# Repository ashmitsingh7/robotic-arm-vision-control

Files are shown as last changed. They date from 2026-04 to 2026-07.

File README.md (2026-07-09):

# Real-Time Robotic Arm Control using MediaPipe Hand Tracking

A computer vision-based robotic arm control system that enables real-time hand gesture control using **MediaPipe**, **OpenCV**, and an **ESP32** over Wi-Fi. The project demonstrates an intuitive human-robot interaction pipeline by translating hand movements captured from a webcam into robotic arm motions.

---

## Overview

This project combines computer vision and embedded systems to create a wireless robotic arm control interface.

Using a standard webcam, the system detects hand landmarks with MediaPipe and maps them to robotic arm movements. Motion commands are transmitted wirelessly to an ESP32, which controls the actuators in real time.

### Key Features

- Real-time hand landmark detection
- Wireless communication with ESP32 over Wi-Fi
- Low-latency robotic arm control
- Computer vision-based human-robot interaction
- Modular software architecture
- OpenCV visualization and debugging

---

## System Architecture

```
Webcam
   │
   ▼
OpenCV Video Stream
   │
   ▼
MediaPipe Hand Tracking
   │
   ▼
Gesture & Landmark Processing
   │
   ▼
Motion Mapping
   │
   ▼
Wi-Fi Communication
   │
   ▼
ESP32 Controller
   │
   ▼
Servo Motors
   │
   ▼
Robotic Arm
```

---

## Repository Contents

| File | Description |
|---|---|
| `vision_control.py` | Main computer vision and control program |
| `esp_wifi.ino` | ESP32 firmware for wireless communication |
| `babyarm_nano.ino` | Arduino Nano firmware |
| `robotic_arm_full_architecture.svg` | System architecture diagram |
| `3d_RoboticArm.f3d` | Fusion 360 CAD model |
| `MPMC_Report_Final.pdf` | Project documentation |

---

## Technologies Used

### Software

- Python
- OpenCV
- MediaPipe
- NumPy

### Hardware

- ESP32
- Arduino Nano
- Servo Motors
- USB Webcam
- Custom Robotic Arm

---

## Installation

Clone the repository

```bash
git clone https://github.com/ashmitsingh7/robotic-arm-vision-control.git
cd robotic-arm-vision-control
```

Install the required Python packages.

```bash
pip install opencv-python mediapipe numpy
```

Upload the appropriate firmware to the ESP32 and Arduino Nano before running the Python application.

Start the vision controller.

```bash
python src/vision_control.py
```

---

## Working Principle

1. Capture live video using a webcam.
2. Detect hand landmarks with MediaPipe.
3. Convert landmark positions into robotic arm commands.
4. Send commands over Wi-Fi to the ESP32.
5. Control the robotic arm in real time.

---

## Applications

- Human-Robot Interaction
- Gesture-Based Robot Control
- Educational Robotics
- Embedded Systems
- Computer Vision
- Robotic Manipulation

---

## Future Improvements

- Inverse Kinematics
- ROS 2 Integration
- Object Detection and Grasping
- Depth Camera Support
- Closed-Loop Position Control
- Multi-Hand Gesture Recognition

---

## License

This project is licensed under the MIT License.

---

## Author

**Ashmit Singh**

B.Tech Electronics Engineering (VLSI Design & Technology)

Interested in Robotics, Computer Vision, Embedded Systems, and Intelligent Automation.

GitHub: https://github.com/ashmitsingh7

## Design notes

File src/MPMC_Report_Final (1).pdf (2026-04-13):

# Gesture-Controlled Robotic Arm

### Using Computer Vision and ESP32

Microprocessors and Microcontrollers - Project Report

Team Members
Ashmit Singh | 24BVD0027 | Stavyansh Mishra | 24BEC0169
S. Tarun | 24BVD0008 | Anandita Kaushal | 24BEC0613

### 1. Abstract

Traditional robotic arms are controlled via joysticks or pre-programmed sequences methods that are nonintuitive and require prior technical training. This project presents the design and implementation of a 4-Degree-of-Freedom (4-DOF) Gesture-Controlled Robotic Arm using computer vision and an ESP32 microcontroller, enabling real-time intuitive control through natural hand gestures captured by a standard 2D webcam.

MediaPipe Hands detects 21 hand landmarks per frame at 30 FPS. Finger extension ratios are mathematically mapped to servo angles (0°–180°) for shoulder, elbow, wrist/turntable, and gripper joints. A 7 byte binary packet is transmitted wirelessly via TCP/Wi-Fi to the ESP32, which bridges the command to an Arduino Nano over UART. The Nano drives four servo motors (MG995 × 3 and SG90 × 1) using hardware PWM, achieving end-to-end latency under 100 ms. The system is fully built from low-cost components and 3D-printed structures, aligning with SDG 4, SDG 8, and SDG 9.

### 2. Literature Survey

Five peer-reviewed papers from IEEE and Springer proceedings (2021–2026) relevant to gesture-controlled robotics, embedded vision systems, and Wi-Fi-based servo control are surveyed below.

Year | Title of the Paper | Methodology / Approach | Key Findings | Limitations
2025 | Gesture-Controlled Robotic Arm for Small Assembly Lines Angelidis & Bampis | RGB-D camera; ROS + MoveIt! IK; 7-DOF Panda cobot; 3-D skeletal hand model | High-precision assembly manipulation; full 3-D spatial awareness | Cost > $20,000; requires GPU + ROS; not portable to embedded systems
2023 | Real-Time Hand Gesture Recognition for Robotic Arm — IEEE ICCCNT

MediaPipe Hands; CNN
gesture classifier; Arduino serial link

94.7% accuracy; ~85 ms
pipeline latency

Single hand only; fixed
gesture vocabulary; no
wireless link

2022 Vision-Based Robotic Arm Control with OpenCV Springer CCIS Vol. 1612

OpenCV Haar cascade +
contour detection; 3-DOF
arm via USB serial

Glove-free 2-D camera
control proven feasible at low cost

Sensitive to lighting and
background; no wireless
link

2023 ESP32-Based IoT Robotic Arm with Wi-Fi Control IEEE TENSYMP

ESP32 TCP socket server;
multi-channel PWM; webdashboard interface

Sub-100 ms wireless
latency; multi-servo
simultaneous control
confirmed

Web UI only not gesturedriven; no vision
integration
2024 | Human-Robot Interaction via Hand Landmark Tracking IEEE ICDCS

MediaPipe landmark-toangle mapping; ESP32
PWM; UART 7-byte
packet protocol

Finger-to-joint angle
validated; operates
without ROS or Linux

No smoothing filter;
commercially sourced arm;
single hand only

### 3. Methodology

(i) Block Diagram Hardware Framework
The system converts hand gestures into physical arm motion through seven sequential stages:
- Hand Gesture (Input): The user's hand posture is the sole control input.
- Camera Module: A 2-D USB webcam streams video at 30 FPS to the host PC.
- Gesture Processing (Python / OpenCV / MediaPipe): 21 hand landmarks detected per frame; finger extension ratios linearly mapped to target servo angles (0°–180°).
- TCP / Wi-Fi Communication: A 7-byte packet [0xFF, W, Sh, El, TT, Gr, 0xFE] is transmitted over a TCP socket (port 1234) to the ESP32's IP address.
- ESP32 (UART Bridge): Validates the packet and forwards bytes to the Arduino Nano via HardwareSerial2 (GPIO 16 / 17, 9600 baud).
- Arduino Nano (Servo Controller): Parses the 7-byte packet and writes constrained PWM angles to each servo pin via the Servo library.
- Robotic Arm (Output): Base, shoulder, elbow, and gripper joints articulate in real time to replicate the hand gesture.

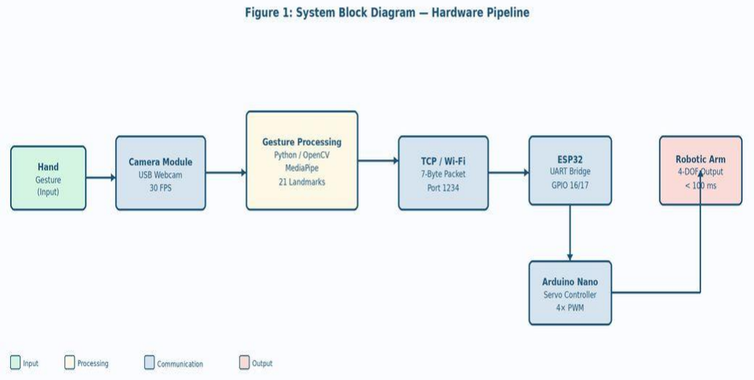
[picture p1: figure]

Figure 1: System Block Diagram — Hardware Pipeline

(ii) Flowchart Software Execution Pipeline
The flowchart below details the complete software pipeline from initialisation to servo actuation, including all decision points.

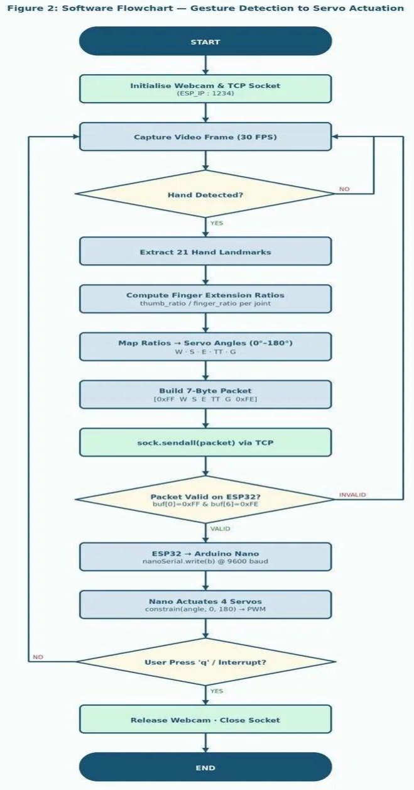
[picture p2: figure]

Figure 2: Software Flowchart — Gesture Detection to Servo Actuation

(iii) Software Code
Three code modules form the complete system. Language: C++ (Arduino IDE 2.x) for microcontrollers; Python 3.x for the host-side gesture recognition.

Listing 1 · mpmccode_tcp.py- Python Gesture Recognition & TCP Client

import cv2, mediapipe as mp, numpy as np, socket

ESP_IP, PORT, START, END = '10.212.176.238', 1234, 255, 254 sock = socket.socket(socket.AF_INET, socket.SOCK_STREAM) sock.connect((ESP_IP, PORT))

hands = mp.solutions.hands.Hands(max_num_hands=1, min_detection_confidence=0.7, min_tracking_confidence=0.7)

def finger_ratio(lm, tip): | # 0.0=down | 1.0=up
return float(np.clip((lm[tip-2].y - lm[tip].y) / (lm[tip-3].y - lm[tip-2].y + 1e-6), 0, 1))
def thumb_ratio(lm): | # uses x-axis
return float(np.clip((lm[3].x - lm[4].x) / (abs(lm[2].x - lm[3].x) + 1e-6), 0, 1))

def send_arm(w,s,e,t,g):
sock.sendall(bytes([START, w, s, e, t, g, END]))

cap = cv2.VideoCapture(0)
while True:
_, frame = cap.read()
frame = cv2.flip(frame, 1)
res = hands.process(cv2.cvtColor(frame, cv2.COLOR_BGR2RGB))
if res.multi_hand_landmarks:
lm = res.multi_hand_landmarks[0].landmark
w = int(np.clip(finger_ratio(lm,12)*180, 0,180)) | # Middle→Wrist
s = int(np.clip(thumb_ratio(lm)*180, | 0,180)) | # Thumb→Shoulder
e = int(np.clip(finger_ratio(lm, 8)*180, 0,180)) | # Index→Elbow
t = int(np.clip(finger_ratio(lm,16)*180, 0,180)) | # Ring→Turntable
g = 180 if finger_ratio(lm,20)>0.5 else 0 | # Pinky→Gripper
send_arm(w, s, e, t, g)
if cv2.waitKey(1) & 0xFF == ord('q'): break
cap.release(); cv2.destroyAllWindows(); sock.close()

Listing 2 · esp_for_serial.ino- ESP32 UART Bridge

#include <Arduino.h>

HardwareSerial nanoSerial(2); | // GPIO16=RX | GPIO17=TX
void setup() {
Serial.begin(115200);
nanoSerial.begin(9600, SERIAL_8N1, 16, 17);
}
void loop() {
while (Serial.available())
nanoSerial.write(Serial.read()); // direct byte forwarding to Nano }

Listing 3 · babyarm_nano.ino- Arduino Nano Servo Controller

#include <Servo.h>

Servo sW, sSh, sTT, sEl, sGr; // Wrist=3 Shoulder=10 TT=6 Elbow=9 Gripper=5 void setup() {
Serial.begin(9600);
sW.attach(3); sSh.attach(10); sTT.attach(6); sEl.attach(9); sGr.attach(5); sW.write(90); sSh.write(90); sTT.write(90); sEl.write(90); sGr.write(90); }
void loop() {
static uint8_t buf[7], idx = 0;
while (Serial.available()) {
uint8_t b = Serial.read();
if (idx==0 && b!=255) continue; // wait for start byte 0xFF buf[idx++] = b;
if (idx==7) {
if (buf[6]==254) { | // validate end byte 0xFE
sW.write(constrain(buf[1],0,180)); sSh.write(constrain(buf[2],0,180)); sEl.write(constrain(buf[3],0,180)); sTT.write(constrain(buf[4],0,180)); sGr.write(constrain(buf[5],0,180)); }
idx = 0;
}
}
}

### 4. Results

(i) CAD Model - Fusion 360 Simulation
The robotic arm was fully modelled in Fusion 360 (project: 3dPrinted_robotArm_step v2) before physical fabrication. The assembly includes a rotative base, ARM_1_L and ARM_2 link segments, three MG-995 servo mounts, one SG-92R gripper assembly, five precision bearings, and M3 base screws. Range-ofmotion limits, servo fitment, and joint clearances were validated in simulation before STL export for 3D printing in PLA.

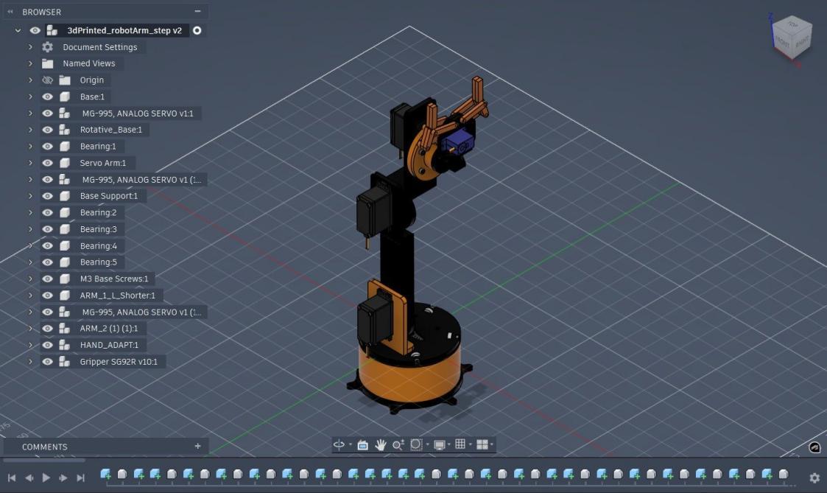
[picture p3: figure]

Figure 3: Fusion 360 CAD Model - 3D Printed Robotic Arm (3dPrinted_robotArm_step v2)

(ii) Hardware Prototype - Physical Assembly
The physical prototype was assembled with 3D-printed PLA structural components, three MG995 servo motors (shoulder, elbow, base turntable), and one SG90 micro servo (gripper). Servo signal wires route internally through the arm links to the Arduino Nano, which connects to the ESP32 over direct UART (GPIO 16/17). During testing all five joints responded accurately and simultaneously to hand gesture commands transmitted over Wi-Fi with measured end-to-end latency of 80–100 ms.

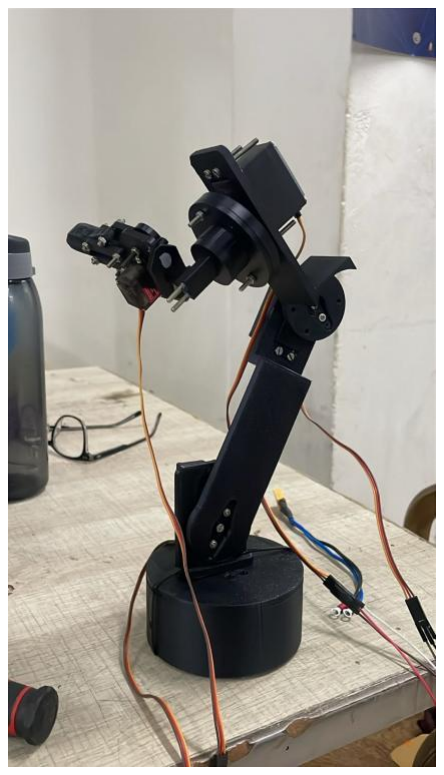
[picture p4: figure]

Figure 4: Hardware Prototype - Assembled 4-DOF Gesture-Controlled Robotic Arm

(iii) System Output - Gesture Recognition in Action
The following photographs capture real-time gesture recognition during live testing. The MediaPipe handtracking pipeline correctly classifies distinct finger configurations and transmits the corresponding servo commands to the robotic arm via Wi-Fi within the measured 80–100 ms end-to-end latency window.

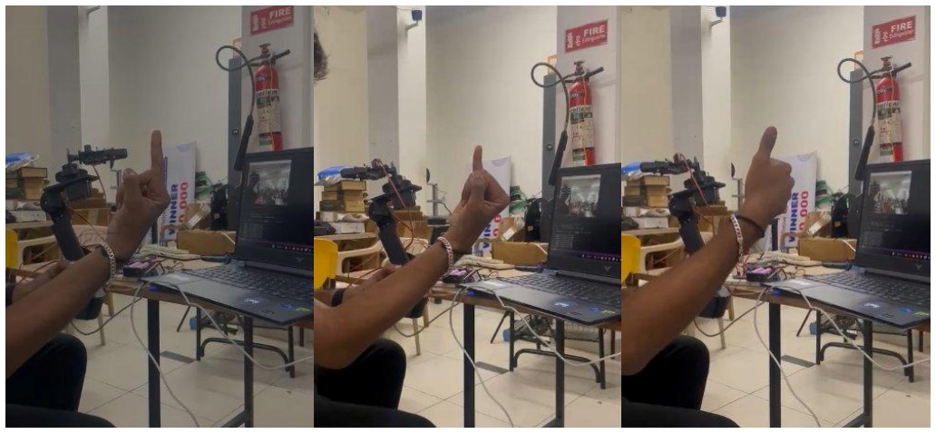
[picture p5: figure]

Figure 5: Live Gesture Recognition -Index-Up, Thumbs-Up, and Thumbs-Up (Side View) detected by MediaPipe and transmitted to the robotic arm

### 5. Conclusion and Future Work

This project successfully demonstrated a complete, end-to-end 4-DOF gesture-controlled robotic arm using computer vision (OpenCV + MediaPipe), a TCP/Wi-Fi communication layer (Python → ESP32), a UART bridge (ESP32 → Arduino Nano), and 3D-printed hardware. The system achieves intuitive, glove-free, controller-free arm control at under 100 ms latency at a cost well below comparable industrial platforms. By eliminating dependency on ROS, dedicated GPU workstations, or RGB-D sensors, the project is readily reproducible in academic and prototyping environments.

The project contributes to SDG 9 (low-cost robotic automation), SDG 8 (productivity through automation), and SDG 4 (affordable hands-on STEM education).

Future Work
- Deep Learning Gesture Recognition: Replace rule-based ratio mapping with CNN/LSTM for complex temporal gestures and improved robustness.
- Reinforcement Learning for Trajectory Optimisation: RL agents to minimise motion time and energy in pick-and-place tasks.
- Autonomous Pick-and-Place: Integrate YOLOv8 object detection for gesture-triggered fully autonomous task execution.
- Dual-Hand Bimanual Control: Extend mapping to both hands for coordinated multi-servo control.
- 6-DOF Mechanical Upgrade: Scale the 3D-printed structure to six degrees of freedom with an additional wrist-rotation joint.

### 6. References

[1] A. Angelidis and E. Bampis, "Gesture-Controlled Robotic Arm for Small Assembly Lines," in Proc. IEEE ICRA, 2025.
[2] R. Sharma, P. Gupta, and A. Mehta, "Real-Time Hand Gesture Recognition for Robotic Arm Control Using MediaPipe and Deep Learning," in Proc. IEEE ICCCNT, 2023, pp. 1–6.
[3] K. Zhang, L. Wei, and S. Liu, "Vision-Based Robotic Arm Control Using Hand Gesture Recognition with OpenCV," Springer CCIS, vol. 1612, pp. 234–245, 2022.
[4] M. Patel, N. Joshi, and H. Singh, "ESP32-Based IoT Robotic Arm with Wi-Fi Control and PWM Servo Management," in Proc. IEEE TENSYMP, 2023, pp. 1–5.
[5] Y. Chen, W. Li, and J. Wang, "Human-Robot Interaction via Hand Landmark Tracking and Embedded PWM Control," in Proc. IEEE ICDCS, 2024, pp. 78–83.

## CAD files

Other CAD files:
src/3d_RoboticArm.f3d

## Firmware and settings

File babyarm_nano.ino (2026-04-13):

#include <Servo.h>
// ===== Servo Objects =====
Servo servoWrist;
Servo servoShoulder;
Servo servoTurntable;
Servo servoElbow;
Servo servoGripper;

// ===== Pins =====
#define WRIST_PIN 3
#define SHOULDER_PIN 10
#define TT_PIN 6
#define ELBOW_PIN 9
#define GRIPPER_PIN 5

// ===== Positions =====
int wristPos = 90;
int shoulderPos = 90;
int ttPos = 90;
int elbowPos = 90;
int gripperPos = 90;

void moveServo(uint8_t joint, uint8_t angle) {

  angle = constrain(angle, 0, 180);

  switch (joint) {

    case 1:
      wristPos = angle;
      servoWrist.write(wristPos);
      break;

    case 2:
      shoulderPos = angle;
      servoShoulder.write(shoulderPos);
      break;

    case 3:
      elbowPos = angle;
      servoElbow.write(elbowPos);
      break;

    case 4:
      ttPos = angle;
      servoTurntable.write(ttPos);
      break;

    case 5:
      gripperPos = angle;
      servoGripper.write(gripperPos);
      break;
  }
}

void setup() {

  Serial.begin(9600);

  servoWrist.attach(WRIST_PIN);
  servoShoulder.attach(SHOULDER_PIN);
  servoTurntable.attach(TT_PIN);
  servoElbow.attach(ELBOW_PIN);
  servoGripper.attach(GRIPPER_PIN);

  // Home position
  servoWrist.write(wristPos);
  servoShoulder.write(shoulderPos);
  servoTurntable.write(ttPos);
  servoElbow.write(elbowPos);
  servoGripper.write(gripperPos);
}
void loop() {

  static uint8_t buffer[7];
  static uint8_t index = 0;

  while (Serial.available()) {

    uint8_t byteIn = Serial.read();

    if (index == 0 && byteIn != 255) {
      continue;
    }

    buffer[index++] = byteIn;

    if (index == 7) {

      if (buffer[6] == 254) {

        wristPos = constrain(buffer[1],0,180);
        shoulderPos = constrain(buffer[2],0,180);
        elbowPos = constrain(buffer[3],0,180);
        ttPos = constrain(buffer[4],0,180);
        gripperPos = constrain(buffer[5],0,180);

        servoWrist.write(wristPos);
        servoShoulder.write(shoulderPos);
        servoElbow.write(elbowPos);
        servoTurntable.write(ttPos);
        servoGripper.write(gripperPos);
      }

      index = 0;
    }
  }
}

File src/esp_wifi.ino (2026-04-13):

#include <Arduino.h>
#include <WiFi.h>

const char* ssid = "Anandita's iPhone";
const char* password = "Anandita";

WiFiServer server(1234);

HardwareSerial nanoSerial(2);

uint8_t buffer[7];
int bufIndex = 0;

void setup() {
  Serial.begin(115200);
  delay(1000);

  Serial.println("=== ESP32 BOOT ===");
  Serial.print("Chip model: "); Serial.println(ESP.getChipModel());
  Serial.print("Free heap: "); Serial.println(ESP.getFreeHeap());

  Serial.println("Starting nanoSerial on pins 16/17 at 9600...");
  nanoSerial.begin(9600, SERIAL_8N1, 16, 17);
  Serial.println("nanoSerial OK");

  Serial.print("Connecting to SSID: ");
  Serial.println(ssid);
  WiFi.begin(ssid, password);

  Serial.print("Connecting...");
  int attempts = 0;
  while (WiFi.status() != WL_CONNECTED) {
    delay(500);
    Serial.print(".");
    Serial.print("["); Serial.print(WiFi.status()); Serial.print("]");
    attempts++;
    if (attempts > 40) {
      Serial.println("\nFAILED after 20s. Status: " + String(WiFi.status()));
      Serial.println("Restarting ESP32...");
      delay(1000);
      ESP.restart();
    }
  }

  Serial.println("\nConnected!");
  Serial.print("IP: "); Serial.println(WiFi.localIP());
  Serial.print("Signal strength (RSSI): "); Serial.print(WiFi.RSSI()); Serial.println(" dBm");
  Serial.print("Gateway: "); Serial.println(WiFi.gatewayIP());

  server.begin();
  Serial.println("TCP server started on port 1234");
  Serial.println("=== READY — waiting for client ===");
}

void loop() {
  WiFiClient client = server.available();

  if (client) {
    Serial.println(">>> Client connected from: " + client.remoteIP().toString());

    while (client.connected()) {

      while (client.available()) {
        uint8_t b = client.read();
        Serial.print("Byte rx: 0x"); Serial.println(b, HEX);

        if (b == 255) {
          bufIndex = 0;
          Serial.println("--- Start byte detected, resetting buffer ---");
        }

        buffer[bufIndex++] = b;
        Serial.print("bufIndex now: "); Serial.println(bufIndex);

        if (bufIndex == 7) {
          Serial.print("Full packet: ");
          for (int i = 0; i < 7; i++) {
            Serial.print(buffer[i]); Serial.print(" ");
          }
          Serial.println();

          if (buffer[0] == 255 && buffer[6] == 254) {
            Serial.println("Packet VALID — forwarding to Nano");
            nanoSerial.write(buffer, 7);
            Serial.println("Nano write done");
          } else {
            Serial.print("Packet INVALID — buffer[0]=");
            Serial.print(buffer[0]);
            Serial.print(" buffer[6]=");
            Serial.println(buffer[6]);
          }

          bufIndex = 0;
        }
      }
    }

    client.stop();
    Serial.println("<<< Client disconnected");
  }
}

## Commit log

2026-04-13 Create vision_control.py
    Implements real-time hand tracking using MediaPipe and maps finger movements to servo angles.
    Includes:
    - Finger ratio calculation for gesture detection
    - Servo angle mapping (0–180 degrees)
    - TCP communication with ESP32
    - OpenCV-based visualization overlay
    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
2026-04-13 Robotic Arm CAD File
    [3d_RoboticArm.f3d]
2026-04-13 Rename 3d_RoboticArm.f3d to src/3d_RoboticArm.f3d
    CAD File for Robotic Arm,printed in PLA
    [3d_RoboticArm.f3d]
2026-07-09 Revise README for real-time robotic arm control
    Updated project title, overview, features, and technologies used sections in README.md to reflect the new focus on real-time robotic arm control using MediaPipe hand tracking.
